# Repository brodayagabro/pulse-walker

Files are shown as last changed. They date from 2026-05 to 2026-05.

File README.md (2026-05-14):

# 🕷️ Pulse Walker

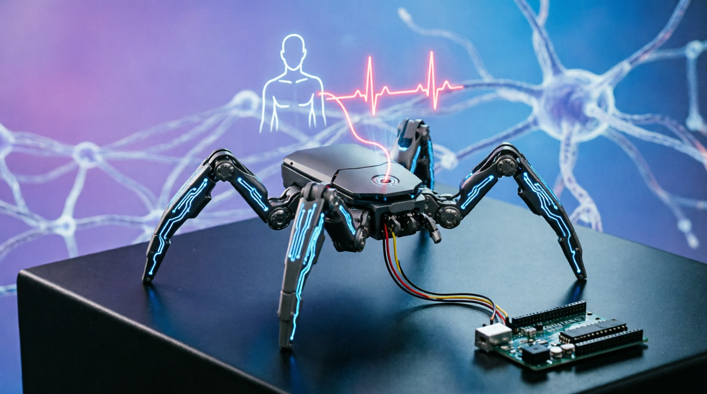
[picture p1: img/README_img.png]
Pulse Walker Banner


**A biofeedback-controlled hexapod robot for neurocognitive training.**

Pulse Walker is a robotic system designed to help users train their autonomic nervous system (ANS) through biological feedback. The robot's locomotion speed is directly modulated by the pilot's physiological state—specifically **Heart Rate (HR)** and **Heart Rate Variability (RMSSD)**.

By controlling the robot's speed through self-regulation (e.g., breathing techniques), the user receives immediate visual and haptic feedback, facilitating the development of vagal tone control and stress resilience.

---

## 🧠 Concept & Workflow

The system operates on a closed biofeedback loop:

1.  **Input:** An ECG sensor captures the pilot's heart rhythm.
2.  **Processing:** An Arduino reads the signal and calculates real-time metrics (`HR`, `RMSSD`) and joystick position (`Vx`, `Vy`).
3.  **Bridge:** A Python GUI application receives this data stream, visualizes the ECG, and acts as a bridge to the robot controller.
4.  **Output:** The robot adjusts its servo oscillation frequency based on the incoming HR or RMSSD values.
    *   *High HR (Excitement)* → Faster movement.
    *   *High RMSSD (Calmness)* → Slower, smoother movement.

---

## 🛠️ Hardware Requirements

| Component | Description | Notes |
| :--- | :--- | :--- |
| **Microcontrollers** | 2x Arduino (Uno, Nano, or Mega) | One for ECG, one for Robot |
| **Hexapod Chassis** | 3-DOF | Modified for 3 servos |
|**Bluetooth module**| HC05(HC06)| conneted to RX\TX on robot controller|
| **Actuators** | 3x MG996R or SG90 Servos | Connected to pins 5, 6, 9 |
| **Sensors** | AD8232 or Bitronics ECG Module | Connected to A0 |
| **Input** | Analog Joystick Module | Connected to ecg Arduino Vx to A5, Vy to A6 |
| **Connectivity** | USB or Bluetooth Serial | Connects Robot Arduino to PC |

### Hexapod
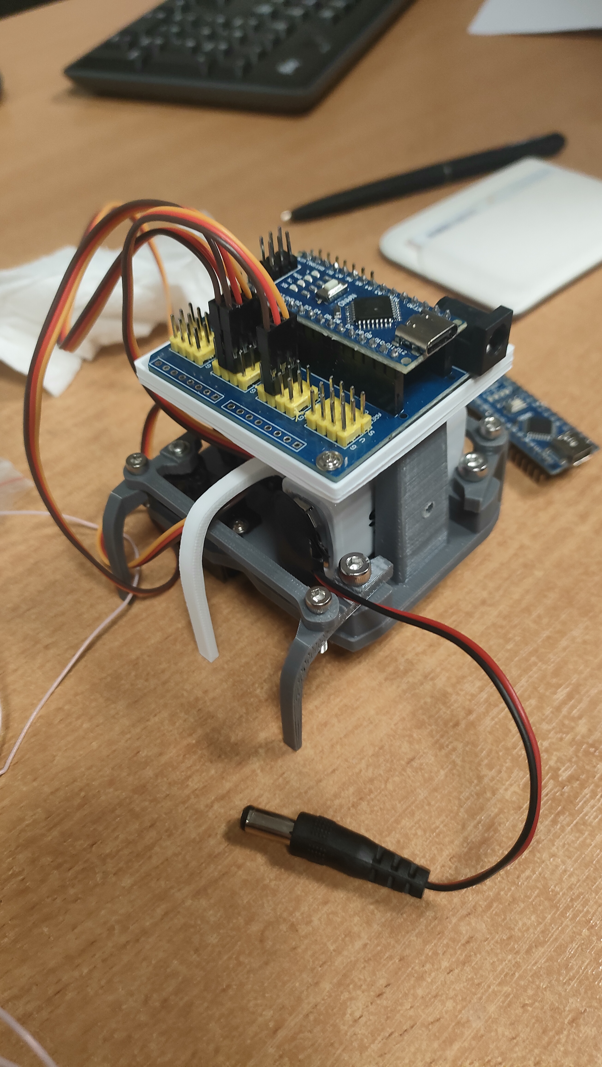
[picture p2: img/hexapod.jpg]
Hexapod setup

---

## 📦 Software Architecture

The system consists of three main parts:

1.  **ECG Module:** Reads sensor data, filters noise (bandpass), and outputs text strings like: `SIG:500 HR:72.5 Vx:512 Vy:400 ...` (`Arduino/ECG_processor`).
2.  **Robot Controller:** Receives commands (`HR:xx`, `RMSSD:xx`, `U`, `L`, `R`, `S`) and drives the servos using a non-blocking state machine(`stl`, `Arduino/bio-robot-control`).
3.  **Python Bridge (`app.py`):** Parses the serial stream, updates the UI, and forwards movement/bio-feedback commands to the robot.

---

## 🚀 Installation & Setup

### 1. Python Dependencies
You will need Python 3.8+.

### 2. Arduino Flashing
Upload the **Robot Controller** sketch (e.g., `bio_robot_control.ino`) to the Arduino connected to your robot.
*   **Servo Pins:** 5 (Right), 6 (Center), 9 (Left).
*   **HC-05 Pins:** 5V(VCC), GND(GND), TX(RX), RX(TX).
*   **Serial Baud Rate:** 9600.

### 3. ECG Module
Upload the ECG processing sketch to your second Arduino. Ensure it is connected to the PC running the bridge software.

---

## 💻 Usage

### Running the GUI
1.  Connect both the ECG module and the Robot module to your computer.
2.  Run the application:
    ```bash
    python app.py
    ```
3.  **Select COM Ports:** Choose the correct ports for "ECG" and "Robot" from the dropdown menus.
4.  **Connect:** Click the `Connect` button.
5.  **Mode Selection:** Use the radio buttons to switch between **HR** (Heart Rate) and **RMSSD** (Variability) as the control parameter.

### Command Protocol
The robot accepts the following commands via Serial:
*   `HR:72.5` - Set frequency based on Heart Rate (60-120 BPM).
*   `RMSSD:45.2` - Set frequency based on RMSSD.
*   `U` - Forward / Active movement.
*   `L` - Turn Left.
*   `R` - Turn Right.
*   `S` - Stop / Reset.

---

## 📦 Building the Executable (PyInstaller)

This project can be compiled into a standalone `.exe` file using **PyInstaller**. This allows you to run the application without having Python installed on the target machine.

### Build Instructions

1.  **Project Structure:**
    Ensure these files are in your root directory:
    *   `app.py` (Main script)
    *   `build.bat` (Build script for Windows)
    *   `build.sh` (Build script for Windows)

2.  **Run the Build:** 
    Run `build.bat`(`build.sh`) from the terminal with conda(*prefer to create a new environment, because `matplotlib, pyserial, pyinstaller` will be installed in your environment*):
    ```cmd
    build.bat
    ```

4.  **Output:**
    If successful, the application will be created in the `dist` folder:
    `dist\pulse-walker\pulse-walker.exe`

   Script will automaticly create lnk-file in build-script folder.

### 🎨 Icon

<p align="center">
  Pulse Walker Icon
</p>   

---

##  Credits
*   **Concept:** Biofeedback Hexapod Control.
*   **Technology:** Arduino, Python, Tkinter, Serial Communication.
*   **License:** MIT License (or insert your license here).

---

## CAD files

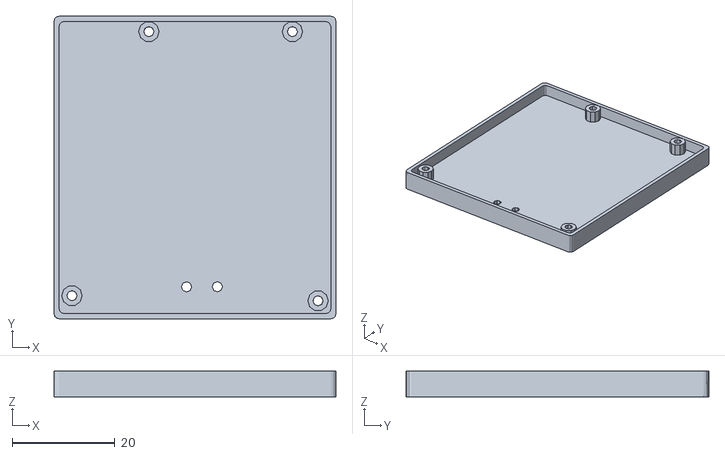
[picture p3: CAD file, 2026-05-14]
stl/arduino_shield.stl
55.0 x 59.0 x 5.00

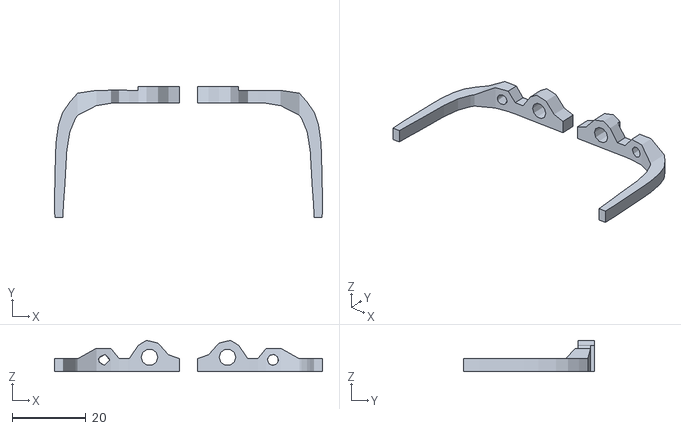
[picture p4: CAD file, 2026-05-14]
stl/beine2.stl
72.4 x 35.3 x 8.47

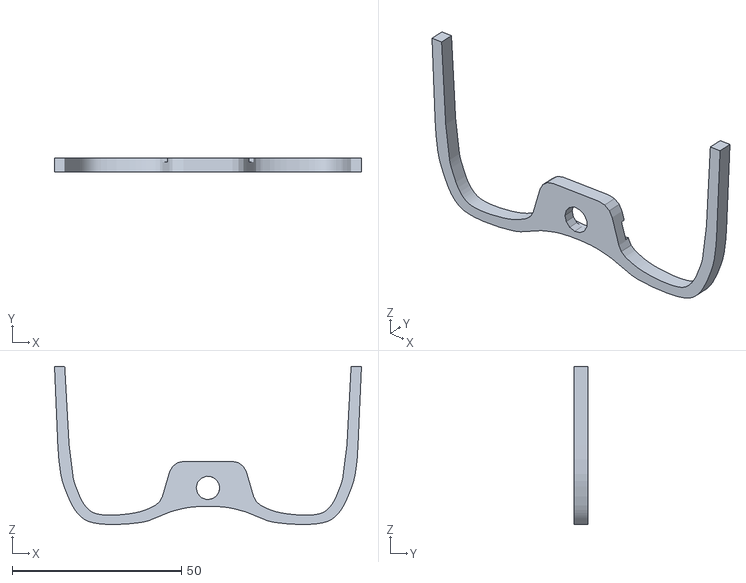
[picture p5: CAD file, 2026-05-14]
stl/1k.stl
90.8 x 4.00 x 46.8

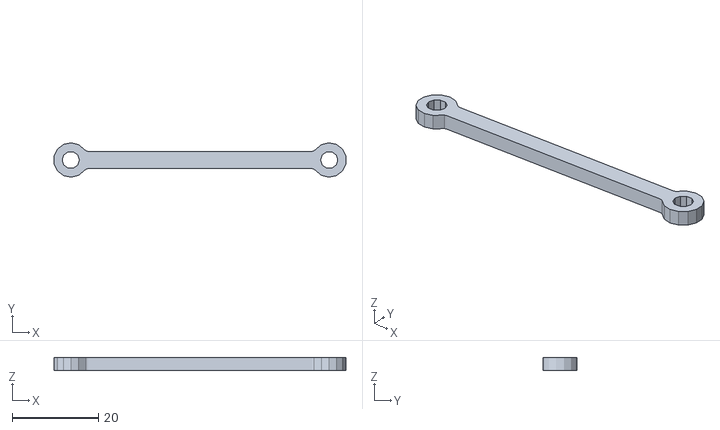
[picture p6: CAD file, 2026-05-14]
stl/connector.stl
67.8 x 8.00 x 3.00

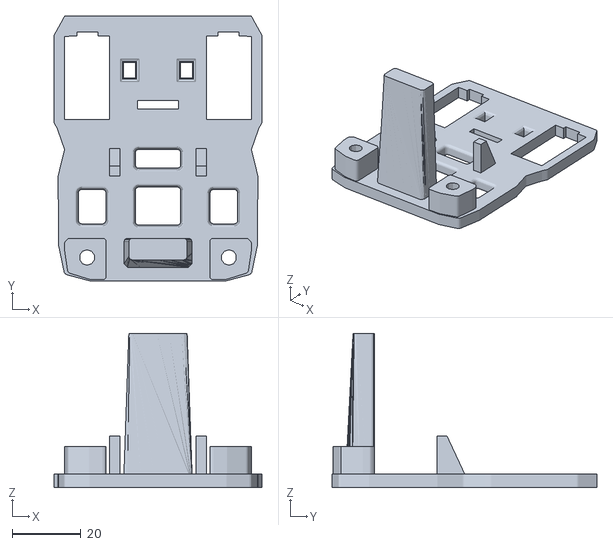
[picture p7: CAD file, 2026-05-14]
stl/2.stl
60.6 x 77.1 x 45.0

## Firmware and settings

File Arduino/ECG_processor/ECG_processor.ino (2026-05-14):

/*
ЭКГ монитор с расчетом ЧСС и ВСР
Исправленная версия: 
- Убран баг RMSSD:nan
- Исправлена адаптация порога
- Упрощён буфер RR-INTERVALS
*/

#include <TimerOne.h>

// ==================== КОНСТАНТЫ ====================
const int SAMPLE_INTERVAL_US = 3000;    // ~333 Гц
const int REFRACTORY_PERIOD_MS = 200;   
const int MIN_RR_INTERVAL_MS = 300;     
const int MAX_RR_INTERVAL_MS = 2000;    
const int RR_BUFFER_SIZE = 10;          

// Параметры фильтра (0.5-40 Гц)
const int HP_ALPHA = 1005;   
const int LP_ALPHA = 439;    
const int FIXED_POINT = 1024;

// Настройки отладки
#define DEBUG_TEXT_OUTPUT true
#define TEXT_UPDATE_INTERVAL_MS 20

// ==================== ГЛОБАЛЬНЫЕ ПЕРЕМЕННЫЕ ====================

// --- Фильтрация ---
int hpPrevInput = 0, hpPrevOutput = 512, lpPrevOutput = 512;

// --- Детектирование ---
int peakThreshold = 700;        // Стартовое значение (адаптируется автоматически)
unsigned long lastPeakTime = 0;
bool inRefractoryPeriod = false;
unsigned long refractoryStartTime = 0;
int previousSignal = 0;

// --- Адаптивный порог ---
float thresholdAlpha = 0.95;        // 0.95 = быстрая адаптация, 0.99 = плавная
const float PEAK_FRACTION = 0.7;    
const int STATS_WINDOW = 50;        // Окно ~150 мс
int signalMin = 1023, signalMax = 0, statsCount = 0;

// --- RR-интервалы (простой массив со сдвигом, без кольцевой математики) ---
unsigned long rrIntervals[RR_BUFFER_SIZE];
int rrCount = 0;

// --- Текущие значения ---
int currentHeartRate = 0;
int currentRRInterval = 0;

// --- Для вывода ---
unsigned long lastTextSendTime = 0;
int debugRR = 0, debugHR = 0;
float debugRMSSD = 0, debugSDNN = 0;
int filteredValue = 0, rawValue = 0;

// --- Показания с джойстика ---
int Vx; int Vy;

// ==================== ФИЛЬТРАЦИЯ ====================
void initBandpassFilter() {
  hpPrevInput = 0; hpPrevOutput = 512; lpPrevOutput = 512;
}

int highPassFilter(int input) {
  int diff = input - hpPrevInput;
  long output = hpPrevOutput + ((long)HP_ALPHA * diff) / FIXED_POINT;
  hpPrevInput = input; hpPrevOutput = constrain(output, 0, 1023);
  return hpPrevOutput;
}

int lowPassFilter(int input) {
  long output = lpPrevOutput + ((long)LP_ALPHA * (input - lpPrevOutput)) / FIXED_POINT;
  lpPrevOutput = constrain(output, 0, 1023);
  return lpPrevOutput;
}

int applyBandpassFilter(int newValue) {
  return lowPassFilter(highPassFilter(newValue));
}

// ==================== АДАПТАЦИЯ ПОРОГА ====================
void updateAdaptiveThreshold(int signal) {
  signalMin = min(signalMin, signal);
  signalMax = max(signalMax, signal);
  statsCount++;

  if (statsCount >= STATS_WINDOW) {
    // Опорное значение: 60% от размаха (min+max)
    int refValue = (int)(PEAK_FRACTION * (signalMin + signalMax));
    
    // Устойчивая формула: thresh = α*old + (1-α)*ref
    peakThreshold = (int)(thresholdAlpha * peakThreshold + (1.0 - thresholdAlpha) * refValue);
    peakThreshold = constrain(peakThreshold, 300, 900); // Защита от выбросов

    // Сброс окна
    signalMin = 1023; signalMax = 0; statsCount = 0;
  }
}

// ==================== ДЕТЕКТИРОВАНИЕ ПИКОВ ====================
bool detectRPeak(int signal) {
  unsigned long currentTime = millis();
  
  // 1. Адаптация порога
  updateAdaptiveThreshold(signal);
  
  // 2. Инициализация первого отсчёта
  if (lastPeakTime == 0) {
    lastPeakTime = currentTime;
    previousSignal = signal;
    return false;
  }
  
  // 3. Рефрактерный период
  if (inRefractoryPeriod) {
    if (currentTime - refractoryStartTime >= REFRACTORY_PERIOD_MS) {
      inRefractoryPeriod = false;
    } else {
      previousSignal = signal;
      return false;
    }
  }
  
  // 4. Детектирование пересечения порога
  bool peakDetected = false;
  if (previousSignal < peakThreshold && signal >= peakThreshold) {
    unsigned long rrInterval = currentTime - lastPeakTime;
    
    // Первый пик или валидный интервал
    if (rrCount == 0 || (rrInterval >= MIN_RR_INTERVAL_MS && rrInterval <= MAX_RR_INTERVAL_MS)) {
      peakDetected = true;
      addRRInterval(rrInterval);
      currentHeartRate = calculateInstantHeartRate(rrInterval);
      currentRRInterval = rrInterval;
      
      lastPeakTime = currentTime;
      inRefractoryPeriod = true;
      refractoryStartTime = currentTime;
    }
  }
  
  previousSignal = signal;
  return peakDetected;
}

// ==================== РАБОТА С RR-ИНТЕРВАЛАМИ ====================
void addRRInterval(unsigned long interval) {
  // Сдвигаем массив (для 10 элементов это мгновенно и надёжно)
  for (int i = RR_BUFFER_SIZE - 1; i > 0; i--) {
    rrIntervals[i] = rrIntervals[i-1];
  }
  rrIntervals[0] = interval;
  if (rrCount < RR_BUFFER_SIZE) rrCount++;
}

// ==================== РАСЧЁТ ЧСС И ВСР (ПРЯМОЙ, БЕЗ NAN) ====================
int calculateInstantHeartRate(unsigned long rrInterval) {
  return (rrInterval == 0) ? 0 : (int)(60000.0 / rrInterval);
}

float calculateSDNN() {
  if (rrCount < 2) return 0.0;
  float mean = 0.0;
  for (int i = 0; i < rrCount; i++) mean += rrIntervals[i];
  mean /= rrCount;
  
  float variance = 0.0;
  for (int i = 0; i < rrCount; i++) {
    variance += sq(rrIntervals[i] - mean);
  }
  return sqrt(variance / rrCount);
}

float calculateRMSSD() {
  if (rrCount < 2) return 0.0;
  float sumSqDiff = 0.0;
  int validDiffs = 0;
  
  for (int i = 1; i < rrCount; i++) {
    long diff = rrIntervals[i] - rrIntervals[i-1];
    sumSqDiff += sq(diff);
    validDiffs++;
  }
  return (validDiffs == 0) ? 0.0 : sqrt(sumSqDiff / validDiffs);
}

// ==================== ОТПРАВКА ДАННЫХ ====================
byte scaleToByte(int value, int minIn, int maxIn) {
  return (byte)constrain(map(value, minIn, maxIn, 0, 255), 0, 255);
}

void sendDebugText() {
  if (!DEBUG_TEXT_OUTPUT) return;
  unsigned long currentTime = millis();
  if (currentTime - lastTextSendTime < TEXT_UPDATE_INTERVAL_MS) return;
  lastTextSendTime = currentTime;
  
  Serial.print("SIG:"); Serial.print(filteredValue);
  Serial.print(" MIN:"); Serial.print(signalMin);
  Serial.print(" MAX:"); Serial.print(signalMax);
  Serial.print(" THR:"); Serial.print(peakThreshold);
  Serial.print(" RR:"); Serial.print(debugRR);
  Serial.print(" HR:"); Serial.print(debugHR);
  Serial.print(" RMSSD:"); Serial.print(debugRMSSD, 1);
  Serial.print(" SDNN:"); Serial.print(debugSDNN, 1);
  Serial.print(" CNT:"); Serial.print(rrCount);
  Serial.print(" Vx:"); Serial.print(Vx);
  Serial.print(" Vy:"); Serial.println(Vy);
  
}

void sendDebugCommands(){
    if (!DEBUG_TEXT_OUTPUT) return;
  unsigned long currentTime = millis();
  if (currentTime - lastTextSendTime < TEXT_UPDATE_INTERVAL_MS) return;
    lastTextSendTime = currentTime;
  
  Serial.print("SIG:"); Serial.print(filteredValue);
  // Serial.print(" MIN:"); Serial.print(signalMin);
  // Serial.print(" MAX:"); Serial.print(signalMax);
  //Serial.print(" THR:"); Serial.print(peakThreshold);
  //Serial.print(" RR:"); Serial.print(debugRR);
  Serial.print(" HR:"); Serial.print(debugHR);
  Serial.print(" RMSSD:"); Serial.print(debugRMSSD, 1);
  Serial.print(" SDNN:"); Serial.print(debugSDNN, 1);
  //Serial.print(" CNT:"); Serial.print(rrCount);
  Serial.print(" Vx:"); Serial.print(Vx);
  Serial.print(" Vy:"); Serial.println(Vy);
}

void sendByteData() {
  Serial.write("A0"); Serial.write(map(filteredValue, 0, 1023, 0, 255));
  Serial.write("A1"); Serial.write(scaleToByte(currentRRInterval > 0 ? currentRRInterval : 1150, 300, 2000));
  Serial.write("A2"); Serial.write(scaleToByte(currentHeartRate > 0 ? currentHeartRate : 75, 30, 200));
  Serial.write("A3"); Serial.write(scaleToByte((int)(debugRMSSD * 10), 0, 2000));
}


int ecg_pin=A0;
int vy_pin=A5;
int vx_pin=A6;

void sendData() {
  rawValue = analogRead(ecg_pin);
  Vx = analogRead(vx_pin);
  Vy = analogRead(vy_pin);
  filteredValue = applyBandpassFilter(rawValue);
  
  bool peakDetected = detectRPeak(filteredValue);
  
  if (peakDetected) {
    debugRR = currentRRInterval;
    debugHR = currentHeartRate;
  }
  debugRMSSD = calculateRMSSD();
  debugSDNN = calculateSDNN();

  //sendDebugText();
  sendDebugCommands();
  //sendByteData();
}

// ==================== ИНИЦИАЛИЗАЦИЯ ====================
void initAll() {
  Serial.begin(9600);
  initBandpassFilter();
  
  // Сброс буферов
  for(int i=0; i<RR_BUFFER_SIZE; i++) rrIntervals[i] = 0;
  rrCount = 0; lastPeakTime = 0; inRefractoryPeriod = false;
  
  Timer1.initialize(SAMPLE_INTERVAL_US);
  Timer1.attachInterrupt(sendData);
  
  delay(100);
  Serial.println(">> ECG monitor ready (Adaptive Threshold Fixed)");
}

void setup() { initAll(); }
void loop() { /* Всё на прерываниях */ }

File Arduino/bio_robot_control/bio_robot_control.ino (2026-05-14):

/*
Bio-Hexapod: Управление скоростью паука через ЭКГ (HR/RMSSD)
Пилот регулирует вегетативный тонус -> меняет частоту колебаний сервоприводов.
Совместим с выводом ЭКГ-модуля: "SIG:... HR:72 RMSSD:45.2 ..."
*/

#include <Servo.h>
#include <math.h>

// ==================== НАСТРОЙКИ КОНСТРУКЦИИ ====================
const int SERVO_PINS[] = {5, 6, 9};        // Правая, Центр, Левая
const float OFFSETS[]    = {90.0, 90.0, 90.0}; // Нейтральное положение
float AMPLITUDES[] = {30.0, 12.0, 30.0};  // Базовая амплитуда
const float PHASES[]     = {0.0, 2.5 * PI, 0.0};

// ==================== НАСТРОЙКИ БИОСВЯЗИ ====================
// Выберите источник: 1 = HR (ЧСС), 0 = RMSSD (ВСР)
#define BIO_SOURCE_IS_HR 1  

// Диапазоны для маппинга (подстройте под себя)
#define BIO_MIN_VAL  60.0   // Мин. ЧСС или RMSSD -> МЕДЛЕННО (большой период)
#define BIO_MAX_VAL  120.0  // Макс. ЧСС или RMSSD -> БЫСТРО (малый период)

// Диапазон периода колебаний (мс). Меньше = быстрее.
#define PERIOD_MIN  400.0   // Максимальная скорость (возбуждение)
#define PERIOD_MAX  1200.0  // Минимальная скорость (спокойствие)

// Коэффициент плавности (0.01...0.2). Меньше = плавнее, но медленнее реакция.
#define SMOOTHING_K 0.05    

// ==================== ГЛОБАЛЬНЫЕ ПЕРЕМЕННЫЕ ====================
Servo servos[3];
float currentPeriod = 800.0; // Текущий сглаженный период
float targetPeriod  = 800.0; // Целевой период от био-данных
unsigned long startTime = 0;
bool isRunning = false;
char currentCmd = 'S';       // U, L, R, S

// Буфер для Serial
const byte BUF_SIZE = 48;
char serialBuf[BUF_SIZE];
byte bufIdx = 0;

// ==================== ИНИЦИАЛИЗАЦИЯ ====================
void setup() {
  Serial.begin(9600);
  for (int i = 0; i < 3; i++) {
    servos[i].attach(SERVO_PINS[i]);
    servos[i].write(OFFSETS[i]);
  }
  
  delay(500);
  Serial.println("🕷️ Bio-Hexapod Ready");
  Serial.println("Commands: U=Forward, L=Left, R=Right, S=Stop");
  Serial.println("Bio: Send HR:xx or RMSSD:xx via Serial");
  Serial.println("Mode: M (toggle HR/RMSSD)");
}

// ==================== ОСНОВНОЙ ЦИКЛ ====================
void loop() {
  // 1. Обработка Serial (неблокирующая)
  while (Serial.available()) {
    char c = Serial.read();
    if (c == '\n' || c == '\r') {
      if (bufIdx > 0) processSerialLine();
      bufIdx = 0;
      serialBuf[0] = '\0';
    } else if (bufIdx < BUF_SIZE - 1) {
      serialBuf[bufIdx++] = c;
    }
  }

  // 2. Плавное изменение периода (Low-Pass фильтр)
  currentPeriod += (targetPeriod - currentPeriod) * SMOOTHING_K;

  // 3. Обновление сервоприводов
  unsigned long elapsed = millis() - startTime;
  if (isRunning && currentCmd != 'S') {
    applyCommandBias();
    for (int i = 0; i < 3; i++) {
      float angle = OFFSETS[i] + AMPLITUDES[i] * sin(2.0 * PI * elapsed / currentPeriod + PHASES[i]);
      servos[i].write(constrain(angle, 0, 180));
    }
  } else {
    // Стоп: возврат в нейтраль
    for (int i = 0; i < 3; i++) servos[i].write(OFFSETS[i]);
  }

  // 4. Отладка раз в секунду
  static unsigned long lastDebug = 0;
  if (millis() - lastDebug > 1000) {
    lastDebug = millis();
    Serial.print("CMD:"); Serial.print(currentCmd);
    Serial.print(" PER:"); Serial.print(currentPeriod, 0);
    Serial.print(" TGT:"); Serial.println(targetPeriod, 0);
  }
}

// ==================== ЛОГИКА ====================

void processSerialLine() {
  serialBuf[bufIdx] = '\0';
  char* ptr = serialBuf;

  // Команды управления
  if (strlen(ptr) == 1) {
    char cmd = toupper(ptr[0]);
    if (cmd == 'U' || cmd == 'L' || cmd == 'R') {
      currentCmd = cmd;
      if (!isRunning) { isRunning = true; startTime = millis(); }
      Serial.print(" Move: "); Serial.println(currentCmd);
      return;
    }
    if (cmd == 'S') {
      isRunning = false; currentCmd = 'S';
      Serial.println("🛑 Stop");
      return;
    }
    if (cmd == 'M') {
      // Переключение источника био-данных
      // Логика переключения может быть добавлена при необходимости
      Serial.println("ℹ️ Mode toggle placeholder");
      return;
    }
  }

  // Парсинг био-данных из ЭКГ-потока
  char* hrPtr = strstr(ptr, "HR:");
  char* rmssdPtr = strstr(ptr, "RMSSD:");
  
  float bioVal = 0;
  bool validBio = false;

  if (BIO_SOURCE_IS_HR && hrPtr) {
    bioVal = atof(hrPtr + 3);
    validBio = (bioVal > 0 && !isnan(bioVal));
  } else if (!BIO_SOURCE_IS_HR && rmssdPtr) {
    bioVal = atof(rmssdPtr + 6);
    validBio = (bioVal > 0 && !isnan(bioVal));
  }

  if (validBio) {
    updateTargetPeriod(bioVal);
  }
}

void updateTargetPeriod(float bioValue) {
  // Нормализация в диапазон [0.0 ... 1.0]
  float norm = constrain(bioValue, BIO_MIN_VAL, BIO_MAX_VAL);
  norm = (norm - BIO_MIN_VAL) / (BIO_MAX_VAL - BIO_MIN_VAL);

  // Маппинг на период
  // HR: больше пульс -> быстрее (меньше период)
  // RMSSD: больше вариабельность -> спокойнее (больше период)
  if (BIO_SOURCE_IS_HR) {
    targetPeriod = PERIOD_MAX - norm * (PERIOD_MAX - PERIOD_MIN);
  } else {
    targetPeriod = PERIOD_MIN + norm * (PERIOD_MAX - PERIOD_MIN);
  }
  
  // Ограничители
  targetPeriod = constrain(targetPeriod, PERIOD_MIN, PERIOD_MAX);
}

void applyCommandBias() {
  // Изменяем амплитуды в зависимости от команды поворота
  switch (currentCmd) {
    case 'L': AMPLITUDES[0] = 20.0; AMPLITUDES[2] = 40.0; break; // Левая сильнее
    case 'R': AMPLITUDES[0] = 40.0; AMPLITUDES[2] = 20.0; break; // Правая сильнее
    default:  AMPLITUDES[0] = 30.0; AMPLITUDES[2] = 30.0; break; // Нейтраль
  }
}
